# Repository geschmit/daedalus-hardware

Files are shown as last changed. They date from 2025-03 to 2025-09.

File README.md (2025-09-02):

# Daedalus EDA Files
These are the KiCAD EDA files for Hack Club Cafe's "Daedalus" mystery prize. 
- Pico 2 Form Factor: Identical pinouts, flash size, onboard LED, etc...
- Peripherals: Includes a 6x4 LED matrix, USB-C male connector, and broken-out USB and SWD lines for easy hacking
- Keychainability: Put it on your keyring with a slotted hole on the end!

Latest revision (C) is what was given out to Cafe grant recepients. Prototype revisions A and B are also provided, but it is advised **not to use them** as they contain manufacturing errors and have been left as-is for archival purposes.

Should run the Micro/CircuitPython builds for Pico 2 without a sweat, along with any Pico 2 targetted code.

## LED Matrix Pinout

| Row/Col | GPIO Pin |
|---|---|
| Row 0 | GPIO12 |
| Row 1 | GPIO13 |
| Row 2 | GPIO14 |
| Row 3 | GPIO15 |
| Col 0 | GPIO17 |
| Col 1 | GPIO18 |
| Col 2 | GPIO19 |
| Col 3 | GPIO20 |
| Col 4 | GPIO21 |
| Col 5 | GPIO22 |

## Licensing
Daedalus is shared under two license agreements; only one will apply. Please see each for more information.
- Hack Club Staff & active employees: Daedalus License Agreement. Please contact either me, Acon or current acting Cafe project representative for more information.
- Everybody else: [CC BY-NC-SA 4.0](./LICENSE)

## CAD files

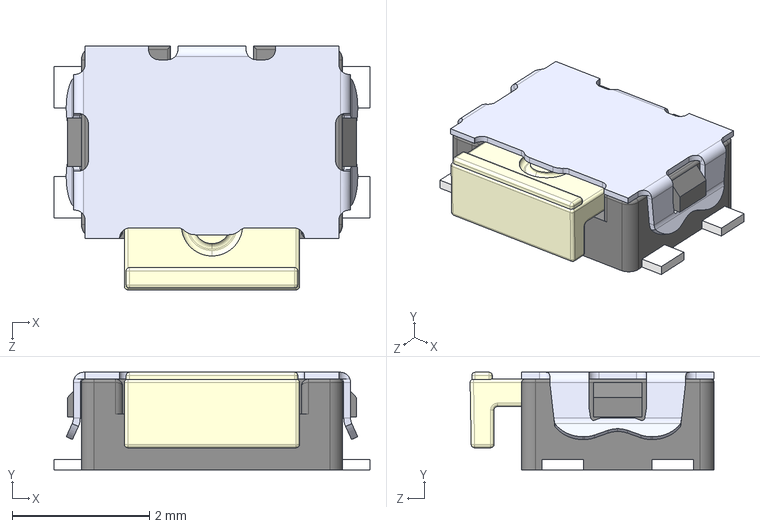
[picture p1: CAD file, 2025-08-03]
rev_c/Parts/KMS221GLFS--3DModel-STEP-56544.STEP
4.60 x 1.42 x 3.55 mm

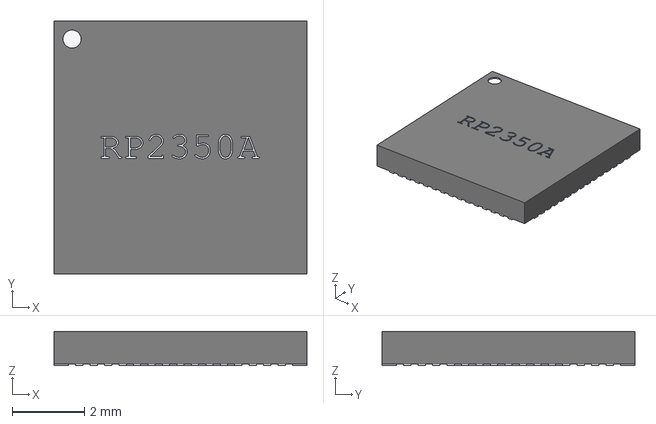
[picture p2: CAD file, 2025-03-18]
rev_c/Parts/RP2350/RP2350_QFN60.step
7.00 x 7.00 x 0.95 mm

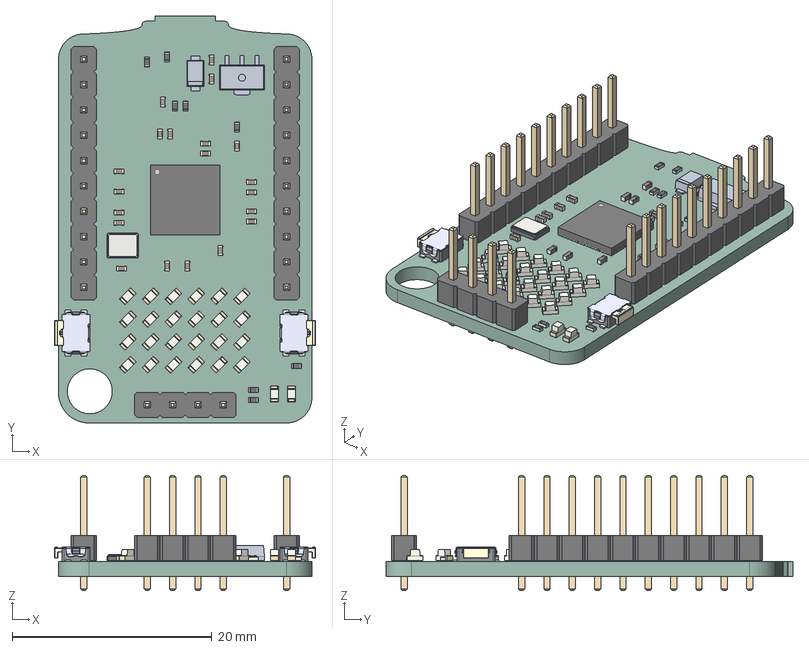
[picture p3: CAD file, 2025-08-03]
rev_c/USBCKeychainAccessory.step
26.2 x 40.8 x 11.5 mm
LED_0603_1608Metric x 26
PinHeader_1x10_P2.54mm_Vertical x 2
C_0402_1005Metric x 20
KMS221GLFS--3DModel-STEP-56544 x 2
R_0402_1005Metric x 8
USBCKeychainAccessory 1.18.1
Crystal_SMD_Abracon_ABM8G-4Pin_3.2x2.5mm
PinHeader_1x04_P2.54mm_Vertical
QFN-56-1EP_7x7mm_P0.4mm_EP5.6x5.6mm
USBCKeychainAccessory 1.55.1
USBCKeychainAccessory_PCB

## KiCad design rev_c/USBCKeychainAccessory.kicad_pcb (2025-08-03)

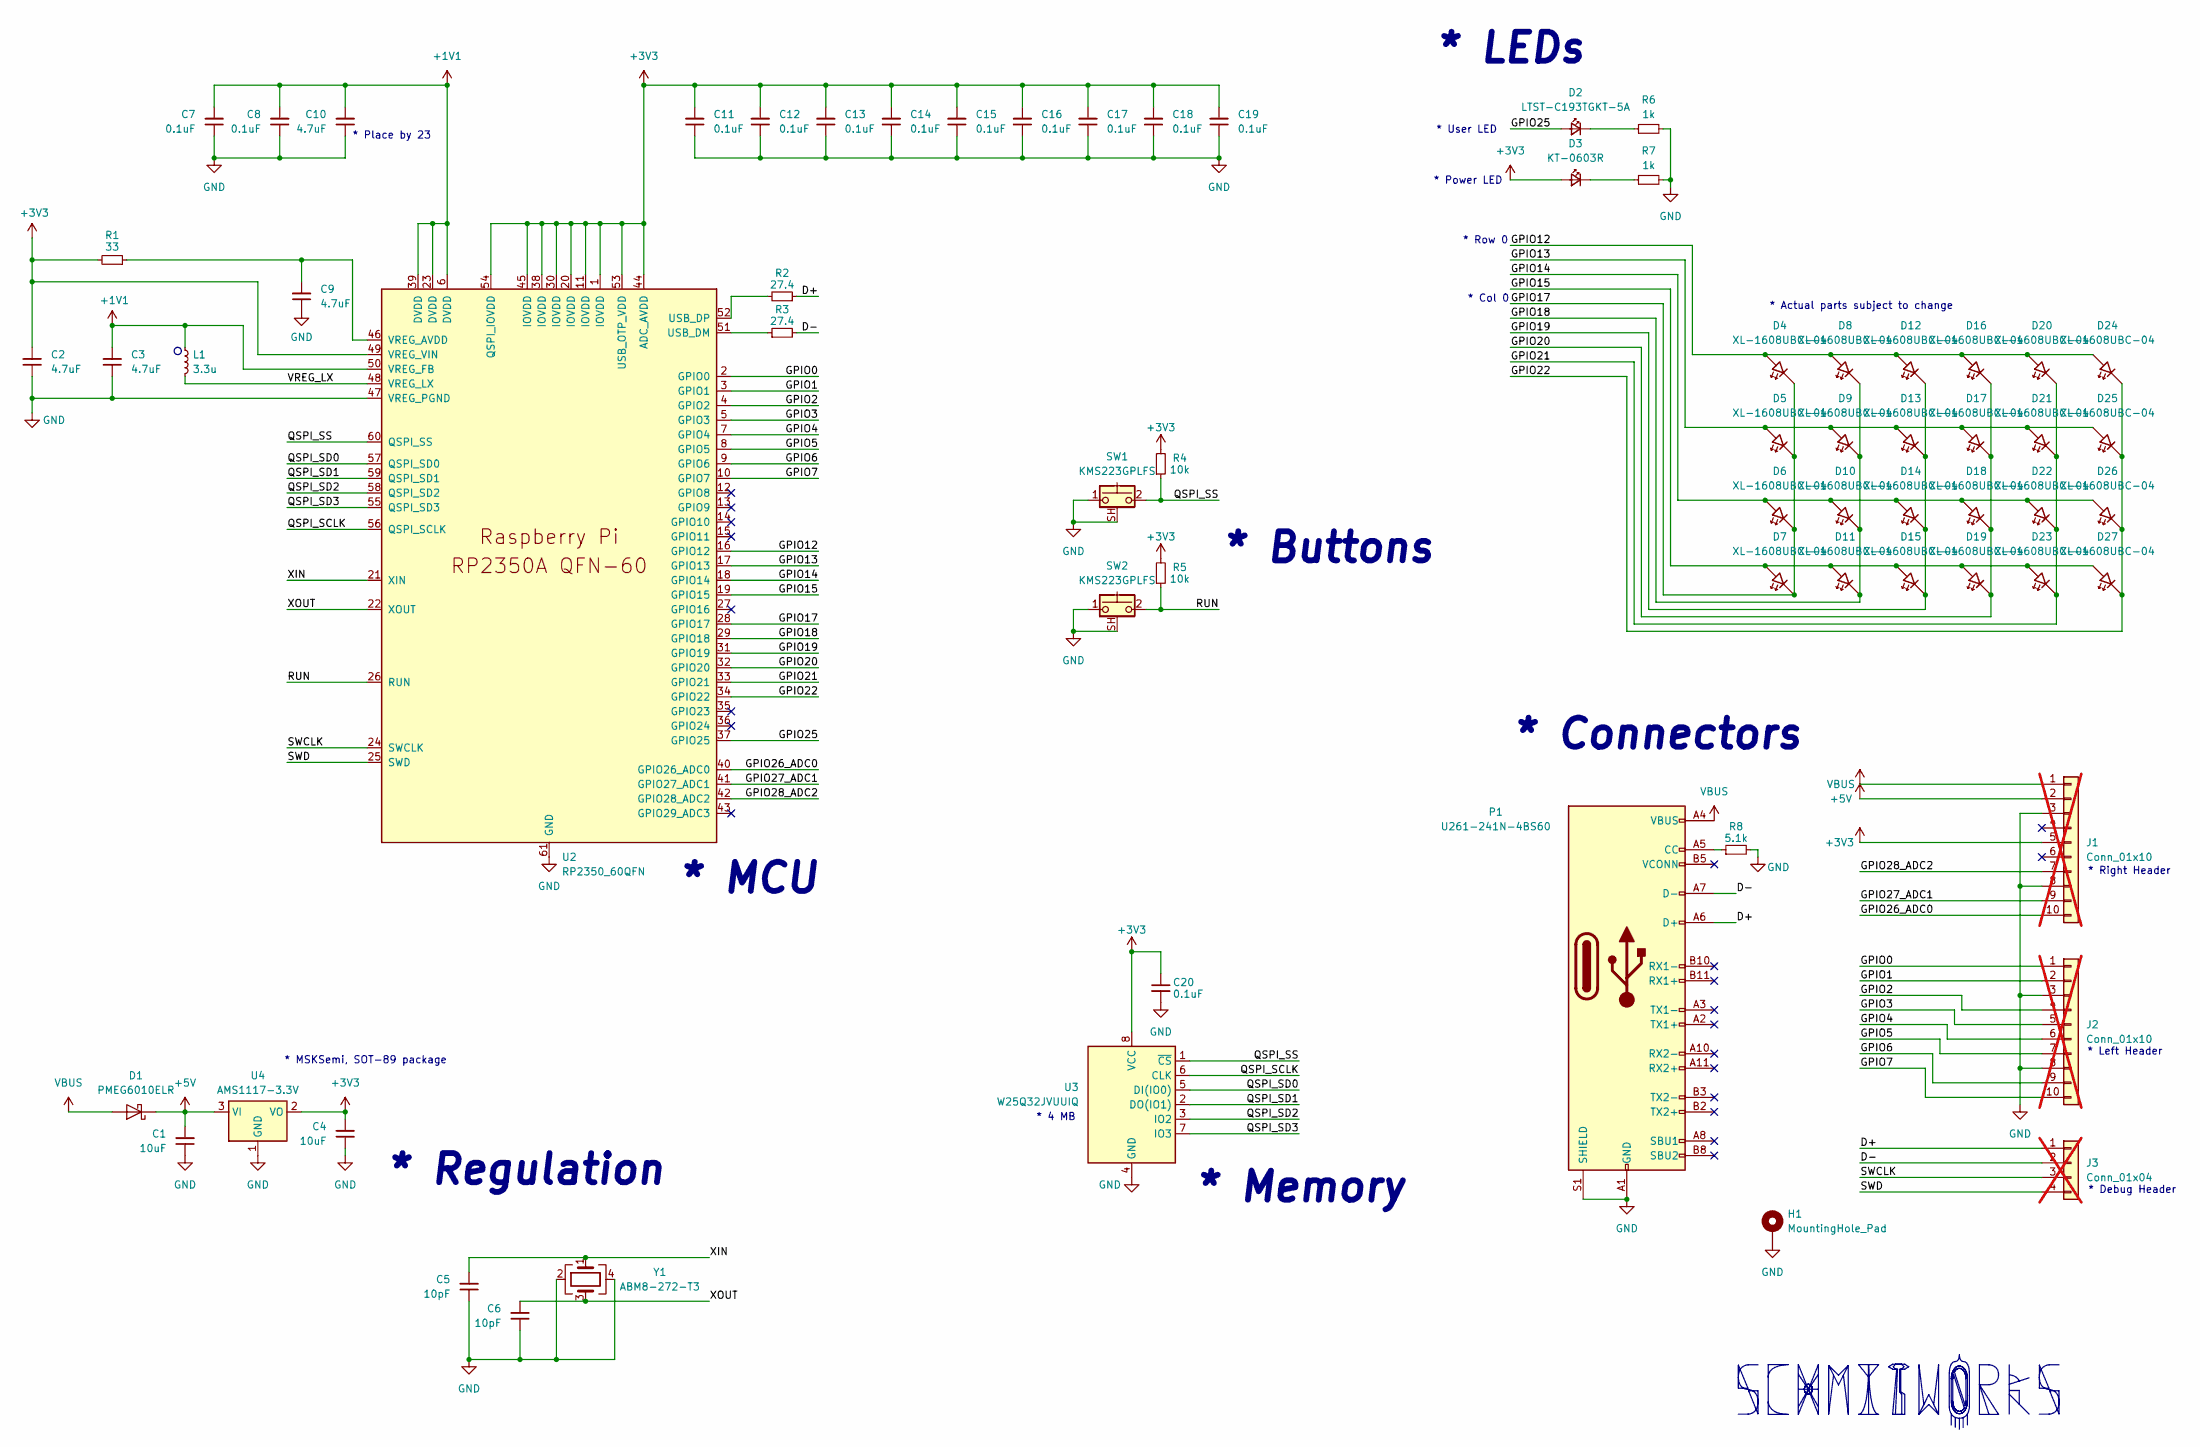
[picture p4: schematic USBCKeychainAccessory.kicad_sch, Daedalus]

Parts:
C1, C4: 10uF; C_0402_1005Metric
C2, C3: 4.7uF; C_0402_1005Metric_small_pads
C5, C6: 10pF; C_0402_1005Metric
C7, C8, C11, C12, C13, C14, C15, C16, C17, C18, C19, C20: 0.1uF; C_0402_1005Metric
C9, C10: 4.7uF; C_0402_1005Metric
D1: PMEG6010ELR; Nexperia_CFP3_SOD-123W
D2: LTST-C193TGKT-5A; LED_0603_1608Metric
D3: KT-0603R; LED_0603_1608Metric
D4, D5, D6, D7, D8, D9, D10, D11, D12, D13, D14, D15, D16, D17, D18, D19, D20, D21, D22, D23, D24, D25, D26, D27: XL-1608UBC-04; LED_0603_1608Metric
H1: MountingHole_Pad; MountingHole_3.2mm_M3_DIN965_Pad
J1, J2: Conn_01x10; PinHeader_1x10_P2.54mm_Vertical; not fitted
J3: Conn_01x04; PinHeader_1x04_P2.54mm_Vertical; not fitted
L1: 3.3u; L_pol_2016
P1: U261-241N-4BS60
R1: 33; R_0402_1005Metric
R2, R3: 27.4; R_0402_1005Metric
R4, R5: 10k; R_0402_1005Metric
R6, R7: 1k; R_0402_1005Metric
R8: 5.1k; R_0402_1005Metric
SW1, SW2: KMS223GPLFS; SW_SPST_CK_KMS2xxGP
U2: RP2350_60QFN; RP2350-QFN-60-1EP_7x7_P0.4mm_EP3.4x3.4mm_ThermalVias
U3: W25Q32JVUUIQ; Winbond_USON-8-2EP_3x4mm_P0.8mm_EP0.2x0.8mm
U4: AMS1117-3.3V; SOT-89-3
Y1: ABM8-272-T3; Crystal_SMD_Abracon_ABM8G-4Pin_3.2x2.5mm

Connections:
+1V1: C3.2, C7.2, C8.2, C10.2, L1.1, U2.6 (DVDD), U2.23 (DVDD), U2.39 (DVDD), U2.50 (VREG_FB)
+3V3: C2.2, C4.2, C11.2, C12.2, C13.2, C14.2, C15.2, C16.2, C17.2, C18.2, C19.2, C20.1, D3.2 (A), J1.5, R1.2, R4.2, R5.2, U2.1 (IOVDD), U2.11 (IOVDD), U2.20 (IOVDD), U2.30 (IOVDD), U2.38 (IOVDD), U2.44 (ADC_AVDD), U2.45 (IOVDD), U2.49 (VREG_VIN), U2.53 (USB_OTP_VDD), U2.54 (QSPI_IOVDD), U3.8 (VCC), U4.2 (VO)
+5V: C1.2, D1.1 (K), J1.2, U4.3 (VI)
/D+: J3.1, P1.A6 (D+), R2.1
/D-: J3.2, P1.A7 (D-), R3.2
/GPIO0: J2.1, U2.2 (GPIO0)
/GPIO1: J2.2, U2.3 (GPIO1)
/GPIO2: J2.4, U2.4 (GPIO2)
/GPIO3: J2.5, U2.5 (GPIO3)
/GPIO4: J2.6, U2.7 (GPIO4)
/GPIO5: J2.7, U2.8 (GPIO5)
/GPIO6: J2.9, U2.9 (GPIO6)
/GPIO7: J2.10, U2.10 (GPIO7)
/GPIO12: D4.2 (A), D8.2 (A), D12.2 (A), D16.2 (A), D20.2 (A), D24.2 (A), U2.16 (GPIO12)
/GPIO13: D5.2 (A), D9.2 (A), D13.2 (A), D17.2 (A), D21.2 (A), D25.2 (A), U2.17 (GPIO13)
/GPIO14: D6.2 (A), D10.2 (A), D14.2 (A), D18.2 (A), D22.2 (A), D26.2 (A), U2.18 (GPIO14)
/GPIO15: D7.2 (A), D11.2 (A), D15.2 (A), D19.2 (A), D23.2 (A), D27.2 (A), U2.19 (GPIO15)
/GPIO17: D4.1 (K), D5.1 (K), D6.1 (K), D7.1 (K), U2.28 (GPIO17)
/GPIO18: D8.1 (K), D9.1 (K), D10.1 (K), D11.1 (K), U2.29 (GPIO18)
/GPIO19: D12.1 (K), D13.1 (K), D14.1 (K), D15.1 (K), U2.31 (GPIO19)
/GPIO20: D16.1 (K), D17.1 (K), D18.1 (K), D19.1 (K), U2.32 (GPIO20)
/GPIO21: D20.1 (K), D21.1 (K), D22.1 (K), D23.1 (K), U2.33 (GPIO21)
/GPIO22: D24.1 (K), D25.1 (K), D26.1 (K), D27.1 (K), U2.34 (GPIO22)
/GPIO25: D2.2 (A), U2.37 (GPIO25)
/GPIO26_ADC0: J1.10, U2.40 (GPIO26_ADC0)
/GPIO27_ADC1: J1.9, U2.41 (GPIO27_ADC1)
/GPIO28_ADC2: J1.7, U2.42 (GPIO28_ADC2)
/QSPI_SCLK: U2.56 (QSPI_SCLK), U3.6 (CLK)
/QSPI_SD0: U2.57 (QSPI_SD0), U3.5 (DI(IO0))
/QSPI_SD1: U2.59 (QSPI_SD1), U3.2 (DO(IO1))
/QSPI_SD2: U2.58 (QSPI_SD2), U3.3 (IO2)
/QSPI_SD3: U2.55 (QSPI_SD3), U3.7 (IO3)
/QSPI_SS: R4.1, SW1.2, U2.60 (QSPI_SS), U3.1 (~CS)
/RUN: R5.1, SW2.2, U2.26 (RUN)
/SWCLK: J3.3, U2.24 (SWCLK)
/SWD: J3.4, U2.25 (SWD)
/VREG_LX: L1.2, U2.48 (VREG_LX)
/XIN: C5.2, U2.21 (XIN), Y1.1
/XOUT: C6.2, U2.22 (XOUT), Y1.3
GND: C1.1, C2.1, C3.1, C4.1, C5.1, C6.1, C7.1, C8.1, C9.1, C10.1, C11.1, C12.1, C13.1, C14.1, C15.1, C16.1, C17.1, C18.1, C19.1, C20.2, H1.1, J1.3, J1.8, J2.3, J2.8, P1.A1 (GND), P1.A12 (GND), P1.B1 (GND), P1.B12 (GND), P1.S1 (SHIELD), R6.2, R7.2, R8.2, SW1.1, SW1.SH (B), SW2.1, SW2.SH (B), U2.47 (VREG_PGND), U2.61 (GND), U3.4 (GND), U4.1 (GND), Y1.2, Y1.4
unnamed: D2.1 (K), R6.1
unnamed: D3.1 (K), R7.1
unnamed: P1.A5 (CC), R8.1
unnamed: R3.1, U2.51 (USB_DM)
unnamed: R2.2, U2.52 (USB_DP)
unnamed: C9.2, R1.1, U2.46 (VREG_AVDD)
VBUS: D1.2 (A), J1.1, P1.A4 (VBUS), P1.A9 (VBUS), P1.B4 (VBUS), P1.B9 (VBUS)

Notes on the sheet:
* Memory
* Row 0
* Regulation
* Buttons
* Connectors
* Col 0
* User LED
* MCU
* Debug Header
* MSKSemi, SOT-89 package
* Place by 23
* Right Header
* 4 MB
* Power LED
* LEDs
* Left Header
* Actual parts subject to change

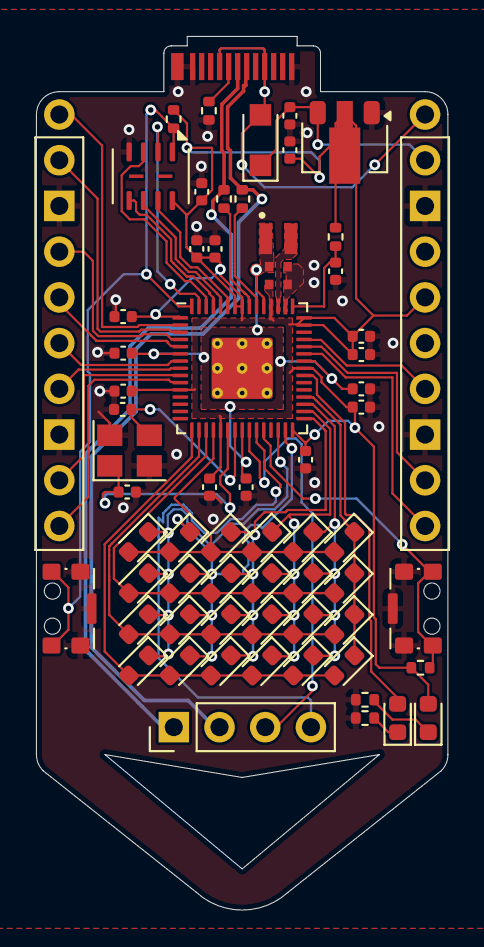
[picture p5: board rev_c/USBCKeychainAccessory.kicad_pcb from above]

Board: 2 copper layers, 22.9 x 48.5 mm, 66 parts (0 on the bottom side), 47 nets.

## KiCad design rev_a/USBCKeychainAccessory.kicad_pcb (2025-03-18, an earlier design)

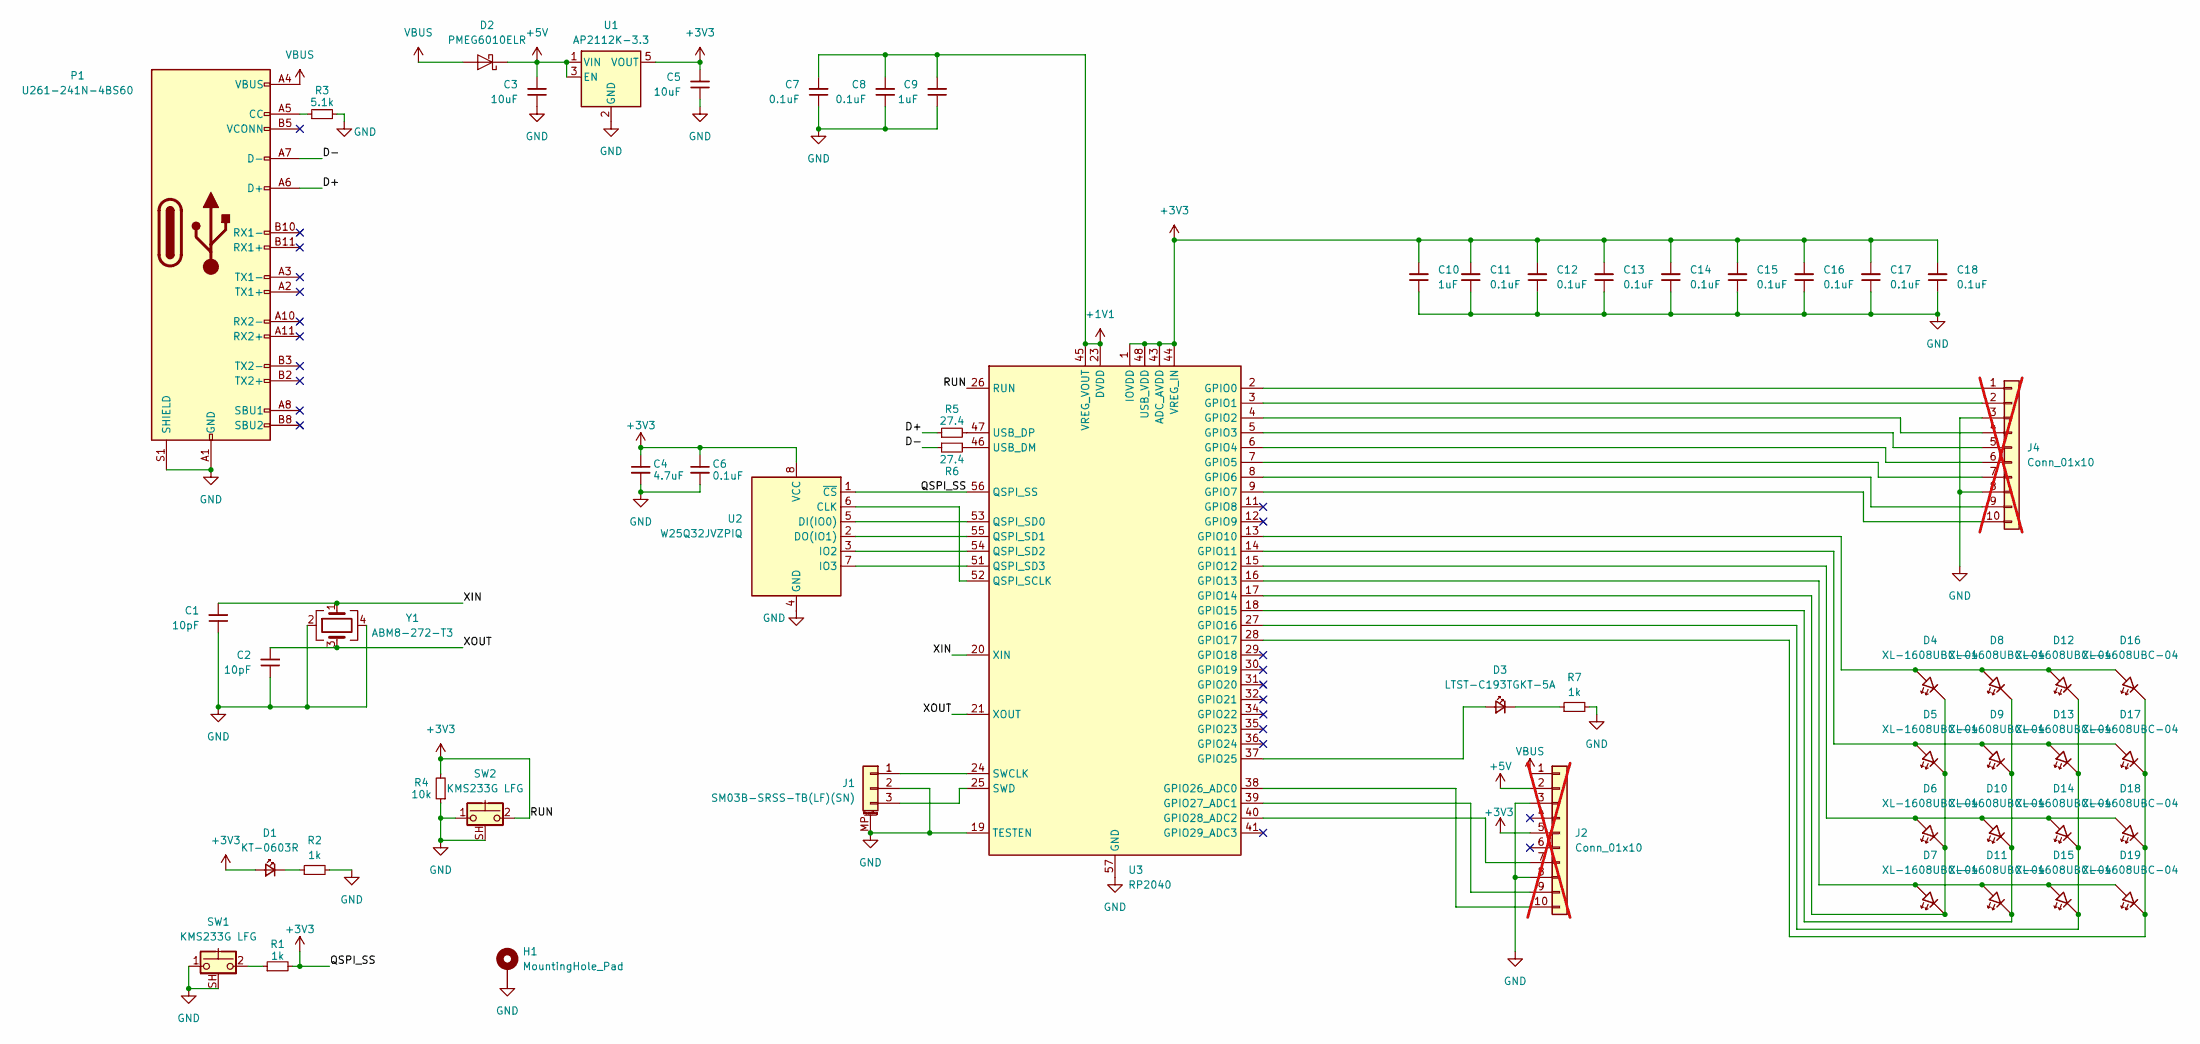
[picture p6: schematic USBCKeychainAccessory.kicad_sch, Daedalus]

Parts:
C1, C2: 10pF; C_0201_0603Metric
C3, C5: 10uF; C_0402_1005Metric
C4: 4.7uF; C_0201_0603Metric
C6, C7, C8, C11, C12, C13, C14, C15, C16, C17, C18: 0.1uF; C_0201_0603Metric
C9, C10: 1uF; C_0201_0603Metric
D1: KT-0603R; LED_0603_1608Metric
D2: PMEG6010ELR; Nexperia_CFP3_SOD-123W
D3: LTST-C193TGKT-5A; LED_0603_1608Metric
D4, D5, D6, D7, D8, D9, D10, D11, D12, D13, D14, D15, D16, D17, D18, D19: XL-1608UBC-04; LED_0603_1608Metric
H1: MountingHole_Pad; MountingHole_2.2mm_M2_DIN965_Pad
J1: SM03B-SRSS-TB(LF)(SN); JST_SH_SM03B-SRSS-TB_1x03-1MP_P1.00mm_Horizontal
J2, J4: Conn_01x10; PinHeader_1x10_P2.54mm_Vertical; not fitted
P1: U261-241N-4BS60
R1, R2, R7: 1k; R_0201_0603Metric
R3: 5.1k; R_0201_0603Metric
R4: 10k; R_0201_0603Metric
R5, R6: 27.4; R_0201_0603Metric
SW1, SW2: KMS233G LFG; SW_SPST_CK_KMS2xxG
U1: AP2112K-3.3; SOT-23-5
U2: W25Q32JVZPIQ; WSON-8-1EP_6x5mm_P1.27mm_EP3.4x4.3mm
U3: RP2040; QFN-56-1EP_7x7mm_P0.4mm_EP3.2x3.2mm
Y1: ABM8-272-T3; Crystal_SMD_Abracon_ABM8G-4Pin_3.2x2.5mm

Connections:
+1V1: C7.2, C8.2, C9.2, U3.23 (DVDD), U3.45 (VREG_VOUT), U3.50 (DVDD)
+3V3: C4.1, C5.2, C6.1, C10.2, C11.2, C12.2, C13.2, C14.2, C15.2, C16.2, C17.2, C18.2, D1.2 (A), J2.5, R1.2, R4.2, SW2.2, U1.5 (VOUT), U2.1 (~CS), U2.8 (VCC), U3.1 (IOVDD), U3.10 (IOVDD), U3.22 (IOVDD), U3.26 (RUN), U3.33 (IOVDD), U3.42 (IOVDD), U3.43 (ADC_AVDD), U3.44 (VREG_IN), U3.48 (USB_VDD), U3.49 (IOVDD), U3.56 (QSPI_SS)
+5V: C3.2, D2.1 (K), J2.2, U1.1 (VIN), U1.3 (EN)
/D+: P1.A6 (D+), R5.1
/D-: P1.A7 (D-), R6.1
/XIN: C1.2, U3.20 (XIN), Y1.1
/XOUT: C2.2, U3.21 (XOUT), Y1.3
GND: C1.1, C2.1, C3.1, C4.2, C5.1, C6.2, C7.1, C8.1, C9.1, C10.1, C11.1, C12.1, C13.1, C14.1, C15.1, C16.1, C17.1, C18.1, H1.MP, J1.2, J1.MP (MountPin), J2.3, J2.8, J4.3, J4.8, P1.A1 (GND), P1.A12 (GND), P1.B1 (GND), P1.B12 (GND), P1.S1 (SHIELD), R2.2, R3.2, R4.1, R7.2, SW1.1, SW1.SH (B), SW2.1, SW2.SH (B), U1.2 (GND), U2.4 (GND), U3.19 (TESTEN), U3.57 (GND), Y1.2, Y1.4
unnamed: D1.1 (K), R2.1
unnamed: D3.2 (A), U3.37 (GPIO25)
unnamed: D3.1 (K), R7.1
unnamed: D4.1 (K), D5.1 (K), D6.1 (K), D7.1 (K), U3.17 (GPIO14)
unnamed: D6.2 (A), D10.2 (A), D14.2 (A), D18.2 (A), U3.15 (GPIO12)
unnamed: D8.1 (K), D9.1 (K), D10.1 (K), D11.1 (K), U3.18 (GPIO15)
unnamed: D7.2 (A), D11.2 (A), D15.2 (A), D19.2 (A), U3.16 (GPIO13)
unnamed: D4.2 (A), D8.2 (A), D12.2 (A), D16.2 (A), U3.13 (GPIO10)
unnamed: D12.1 (K), D13.1 (K), D14.1 (K), D15.1 (K), U3.27 (GPIO16)
unnamed: D5.2 (A), D9.2 (A), D13.2 (A), D17.2 (A), U3.14 (GPIO11)
unnamed: D16.1 (K), D17.1 (K), D18.1 (K), D19.1 (K), U3.28 (GPIO17)
unnamed: J1.1, U3.24 (SWCLK)
unnamed: J1.3, U3.25 (SWD)
unnamed: J2.7, U3.40 (GPIO28_ADC2)
unnamed: J2.9, U3.39 (GPIO27_ADC1)
unnamed: J2.10, U3.38 (GPIO26_ADC0)
unnamed: J4.1, U3.2 (GPIO0)
unnamed: J4.2, U3.3 (GPIO1)
unnamed: J4.4, U3.4 (GPIO2)
unnamed: J4.5, U3.5 (GPIO3)
unnamed: J4.6, U3.6 (GPIO4)
unnamed: J4.7, U3.7 (GPIO5)
unnamed: J4.9, U3.8 (GPIO6)
unnamed: J4.10, U3.9 (GPIO7)
unnamed: P1.A5 (CC), R3.1
unnamed: R1.1, SW1.2
unnamed: U2.6 (CLK), U3.52 (QSPI_SCLK)
unnamed: U2.5 (DI(IO0)), U3.53 (QSPI_SD0)
unnamed: U2.2 (DO(IO1)), U3.55 (QSPI_SD1)
unnamed: U2.3 (IO2), U3.54 (QSPI_SD2)
unnamed: U2.7 (IO3), U3.51 (QSPI_SD3)
unnamed: R6.2, U3.46 (USB_DM)
unnamed: R5.2, U3.47 (USB_DP)
VBUS: D2.2 (A), J2.1, P1.A4 (VBUS), P1.A9 (VBUS), P1.B4 (VBUS), P1.B9 (VBUS)

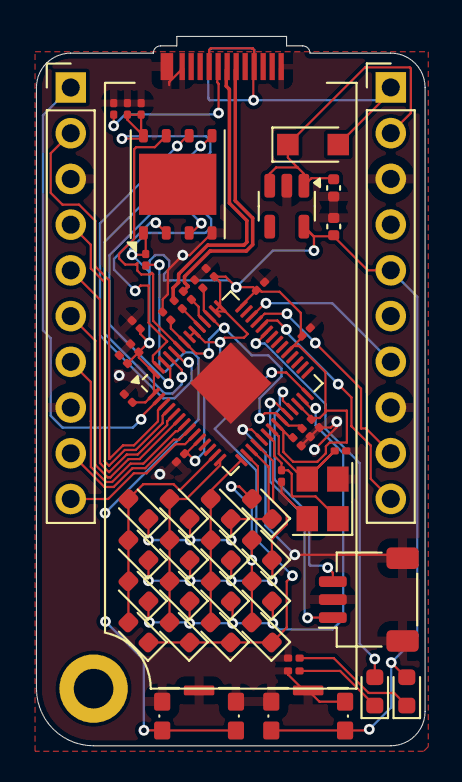
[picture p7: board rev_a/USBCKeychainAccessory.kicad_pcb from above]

Board: 2 copper layers, 21.6 x 39.4 mm, 55 parts (0 on the bottom side), 42 nets.

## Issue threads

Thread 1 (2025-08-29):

Pinout?

m5kro, 2025-08-29:
Is there somewhere I can find the pinout for Daedalus?

geschmit, 2025-08-29:
Yes; it is within the KiCAD files in the repository; you'll want the project in `rev_c`.

You will need to download them and open the project in KiCAD in order to view it, as I have not rendered the schematic to a PDF yet.

Closed 2025-08-29.

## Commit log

2025-03-18 Initial Commit to Source Control
    [KeychainDoohickey.csv, RP2350_QFN60.step, USBCKeychainAccessory.kicad_pcb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]
2025-03-26 Revision B
    [KeychainDoohickey.csv, RP2350_QFN60.step, USBCKeychainAccessory.kicad_pcb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]
2025-08-03 Revision C
    [KMS221GLFS--3DModel-STEP-56544.STEP, RP2350_QFN60.step, USBCKeychainAccessory.kicad_pcb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]
2025-09-01 docs: Add LED Matrix Pinout to README
